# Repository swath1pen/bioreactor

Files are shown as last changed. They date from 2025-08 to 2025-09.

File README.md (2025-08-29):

# 3D Print Design for Customizable Microbial Bioreactor

This design is for a 100mL bioreactor for microbial electrochemical experimentation. 

### NIH 3D Print Database Deposit
https://3d.nih.gov/

### WebApp_beta
https://swath1pen.github.io/bioreactor

## Protocol.io for Fabrication Notes

1. **SLA Printing with FormLabs Printers**

2. **Fabrication of Gaskets**

## License

This project is open source and available under the [MIT License](LICENSE).

---

Happy experimenting!

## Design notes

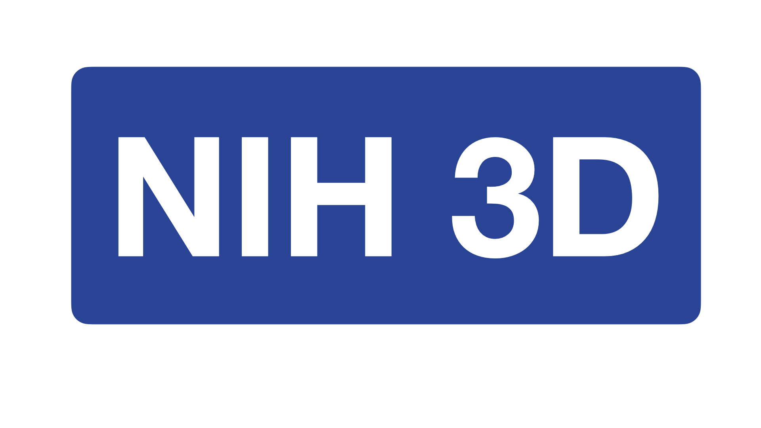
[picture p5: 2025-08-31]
logos/nih.png

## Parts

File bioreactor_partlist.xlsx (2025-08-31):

Purpose | Quantity | Part | Assembly | Link | Price | Quantity | Per Reactor | Price/Reactor
Sealing | 1 | O-Ring: 42 mm Nominal ID, 46 mm Nominal OD. | To seal cap with electrode comprtment and glass bottle. | https://www.grainger.com/product/O-Ring-42-mm-Nominal-Inside-714A76 | 14.13 | 5 | 2 | 5.652
 | 2 | 20mm OD 17m ID silicone custom rubber gasket | Lasercut from silicone sheets purchased from McMasterCarr | https://www.mcmaster.com/1460N11-1460N112/ | 17.13 | 100 | 2 | 0.3426
 | 1 | PTFE-faced silicone septum, 32 mm | To seal electrode compartment with bioreactor cap. | https://www.sigmaaldrich.com/US/en/product/aldrich/z411752 | 52.15 | 10 | 1 | 5.215
Gas Control | 1 | 0.2uM 13mM syringe filters | To ensure sterility during gas exchange. | https://www.thermofisher.com/order/catalog/product/720-1320?ISO_CODE=us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 | 392.62 | 100 | 1 | 3.9262
 | 2 | luer check valve | To control gas pressure release. | https://www.amazon.com/Medical-Grade-Plastic-Female-Diaphragm/dp/B0D78ZLYLP?gQT=1 | 52.61 | 10 | 2 | 10.522
Main Components | 1 | glass bottles 120mL | Main reactor vessel. | https://www.grainger.com/product/41U142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 | 37.21 | 24 | 1 | 1.550416667
 | 1 | Form Labs Biomed Clear Resin | 3D Print Material | https://formlabs.com/store/materials/biomed-clear-resin/ | 349 | 1000 | 60 | 20.94
 | 1 | Titanium wire | Connection to electrodes. | https://www.amazon.com/TEMCo-Titanium-Gauge-Surgical-Resistance/dp/B01AV6RF8M?gQT=1 | 16.7 | 100 | 1 | 0.167
 | 1 | Platinum wire | Counter electrode | https://www.flinnsci.com/platinum-wire-36-gauge-per-inch/p0145/ | 19.25 | 100 | 1 | 0.1925
 | 1 | graphite felt | Working electrode | https://www.avantorsciences.com/ie/en/product/2336090/carbon-99-felt-thickness-6-35-mm-0-250-in | 45 | 100 | 1.7 | 0.765
 | 1 | 20mm CEM FKB-PK-130 | Cation Exchange Membrane | https://www.fuelcellstore.com/fumasep-fkb | 32 | 100 | 1.7 | 0.544
Reference | 1 | Dri-REF2 | Leakless Ag/AgCl reference electrode | https://www.wpiinc.com/driref-2-dri-ref-reference-electrode-2-mm.html | 158 | 1 | 1 | 158
Outer Containment | 1 | Alligator clips | For connection to titanium wire. | https://www.amazon.com/WGGE-WG-026-Pieces-Colors-Alligator/dp/B06XX25HFX?sp_csd=d2lkZ2V0TmFtZT1zcF9hdGY | 5.99 | 10 | 3 | 1.797
 | 1 | Epoxy glue (5 min curing) | To seal clips into mason jar lid. | https://www.amazon.com/dp/B001Z3C3AG?_encoding=UTF8&ref_=cm_sw_r_cp_ud_dp_A05D7AQ3JB35AM0H55W2&th=1 | 5.97 | 1 | 1 | 5.97
 | 1 | tall mason jars | Outer countainment vessel. | https://www.amazon.com/Xylanor-Canning-airtight-Storage-Preserving/dp/B0DS23V3SJ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 | 22.99 | 6 | 1 | 3.831666667
 |  |  |  |  | 1220.75 |  |  | 219.4153833 | Dollars
 |  |  |  |  |  |  |  | 61.41538333

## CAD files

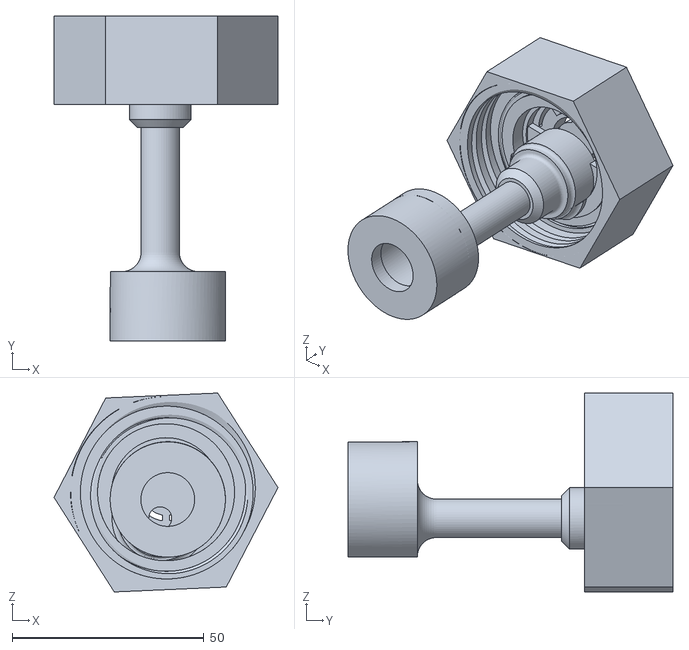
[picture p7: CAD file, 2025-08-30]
dist/bioreactor.stl
58.3 x 84.5 x 51.8

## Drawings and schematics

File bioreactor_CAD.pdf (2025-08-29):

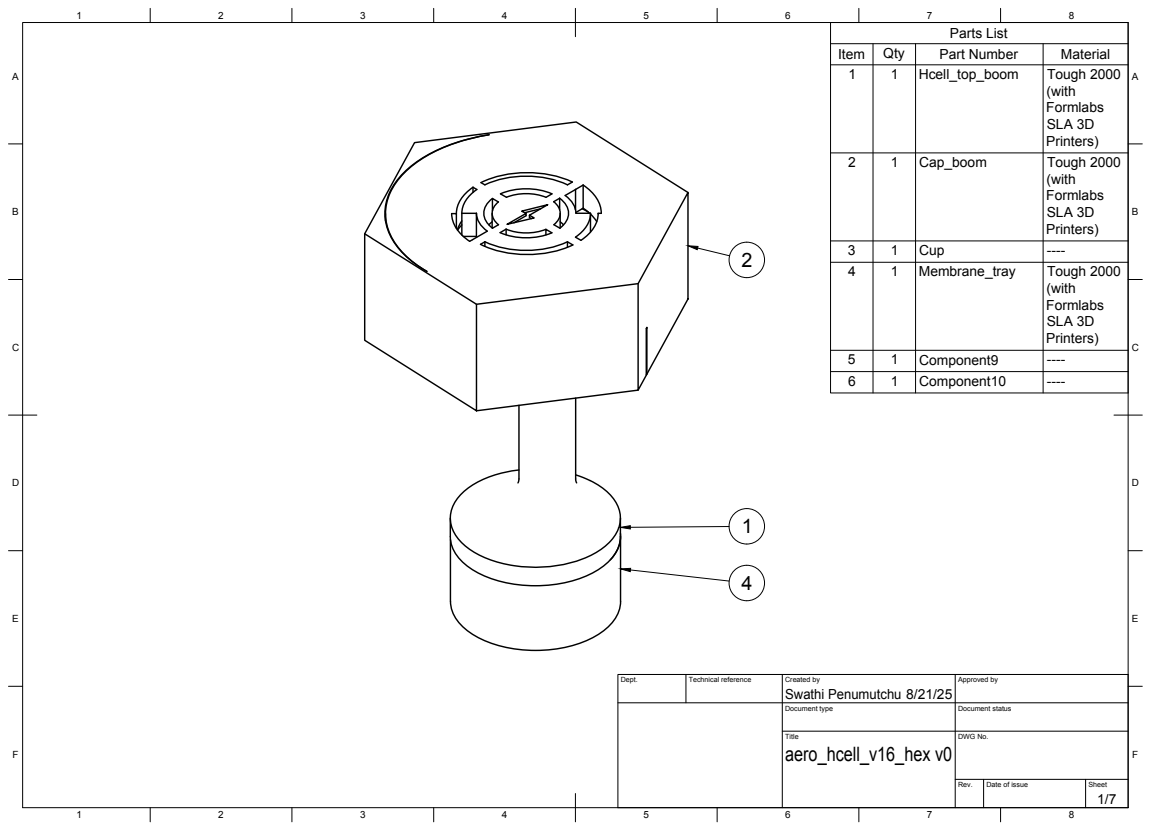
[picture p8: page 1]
Title; DWG No.; Rev.; Date of issue; Sheet; aero_hcell_v16_hex v0; Parts List

Item | Qty 1 | Hcell_top_boom Part Number | Tough 2000 Material 1

(with Formlabs SLA 3D Printers)

2 | 1 | Cap_boom | Tough 2000 (with Formlabs SLA 3D Printers)

3 | 1 | Cup | ----
4 | 1 | Membrane_tray | Tough 2000 (with Formlabs SLA 3D Printers)

5 | 1 | Component9 | ----
6 | 1 | Component10 | ----

Dept. | Technical reference | Created by Swathi Penumutchu 8/21/25 | Approved by

Document type | Document status

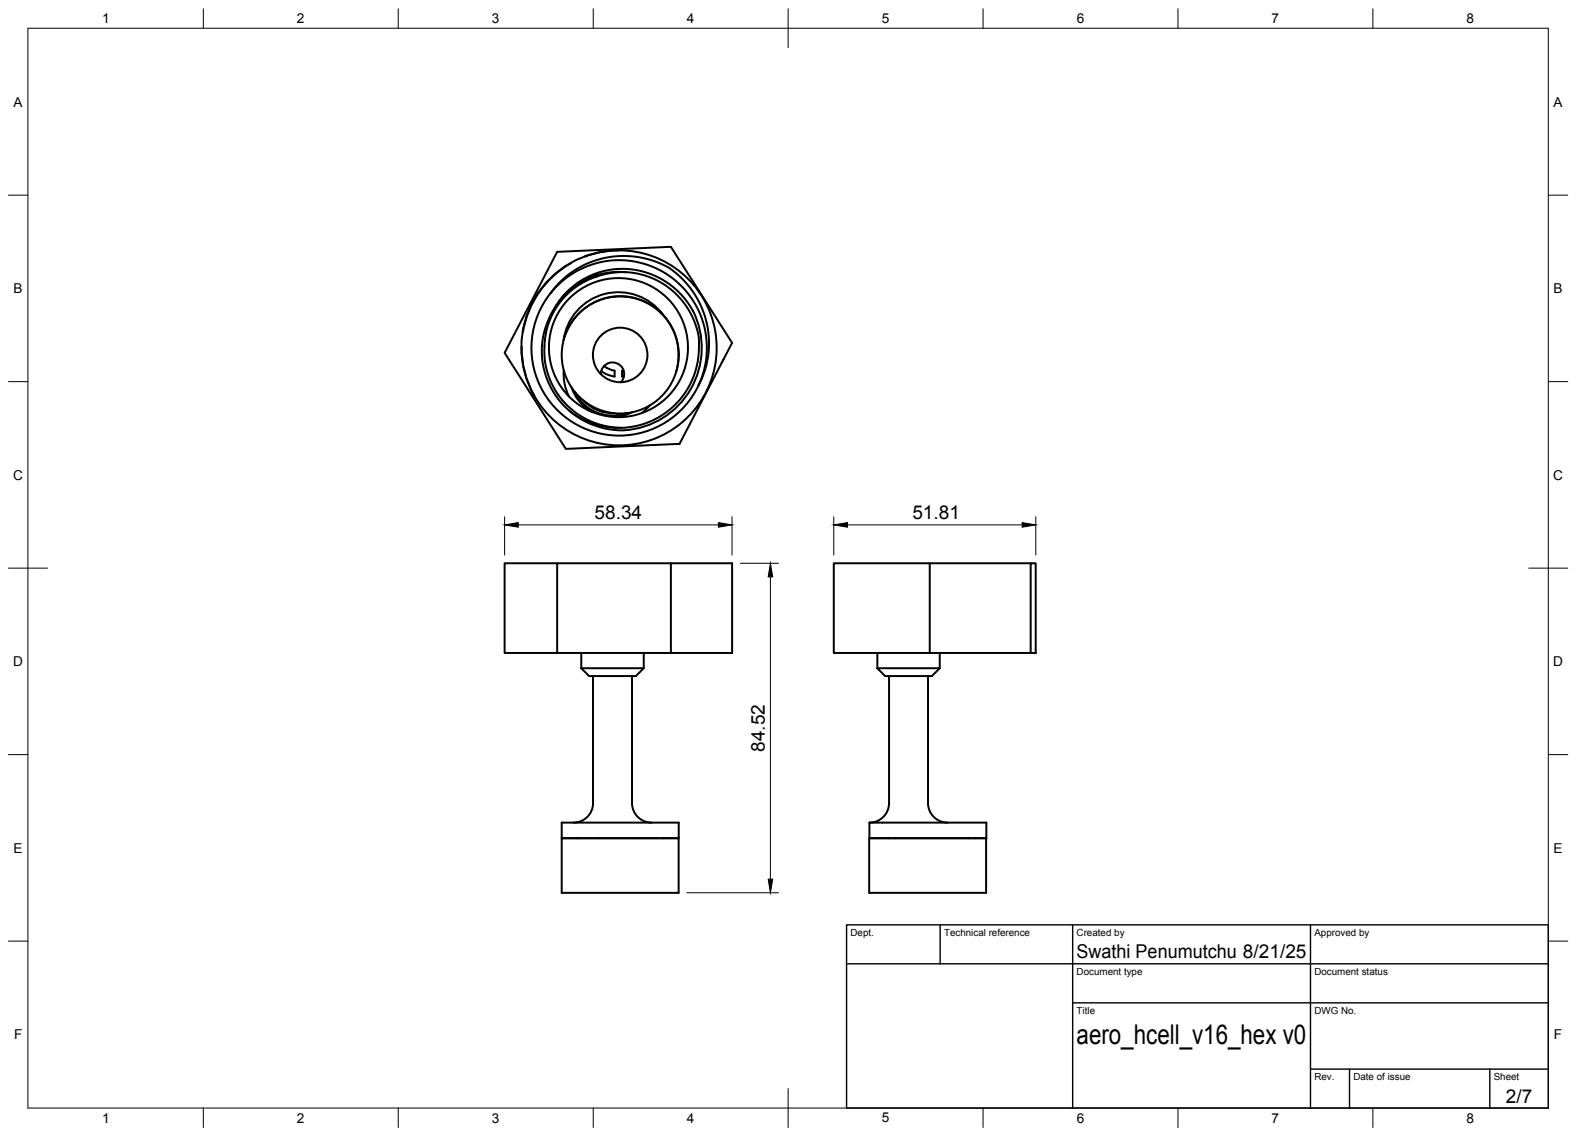
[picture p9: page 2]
Title; DWG No.; aero_hcell_v16_hex v0

Dept. | Technical reference | Created by Swathi Penumutchu 8/21/25 | Approved by

Document type | Document status

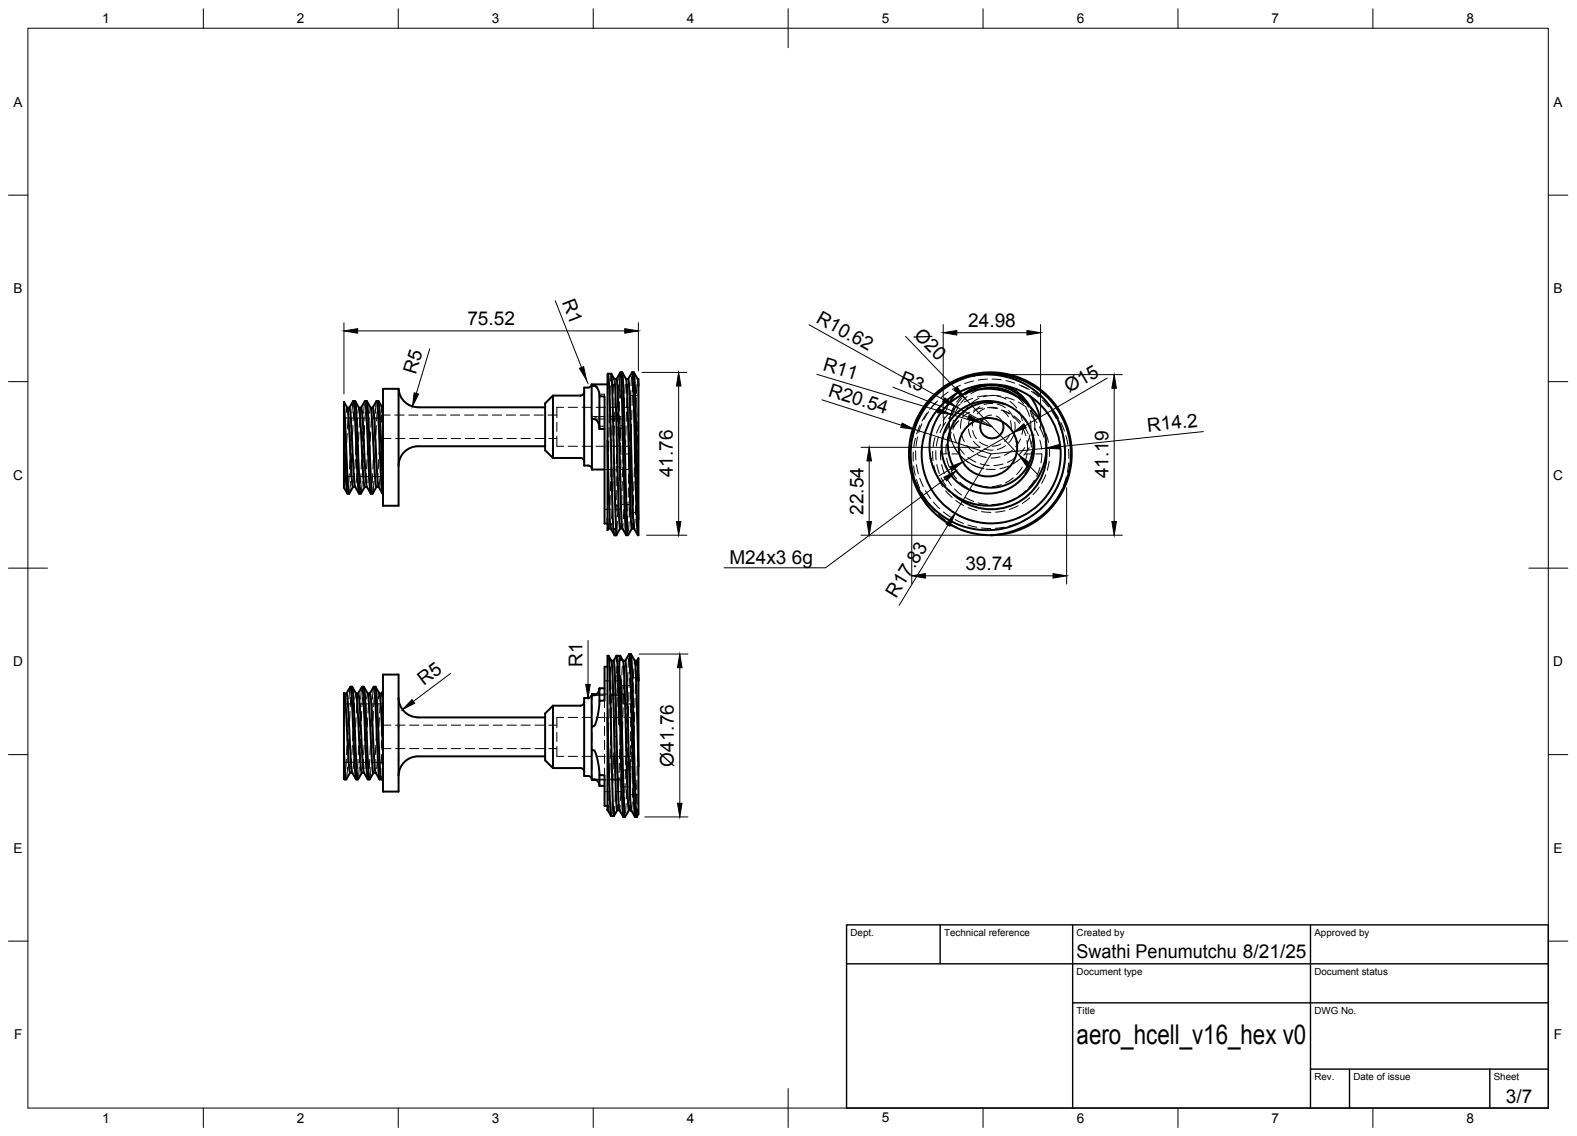
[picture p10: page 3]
Title; DWG No.; aero_hcell_v16_hex v0

Dept. | Technical reference | Created by Swathi Penumutchu 8/21/25 | Approved by

Document type | Document status

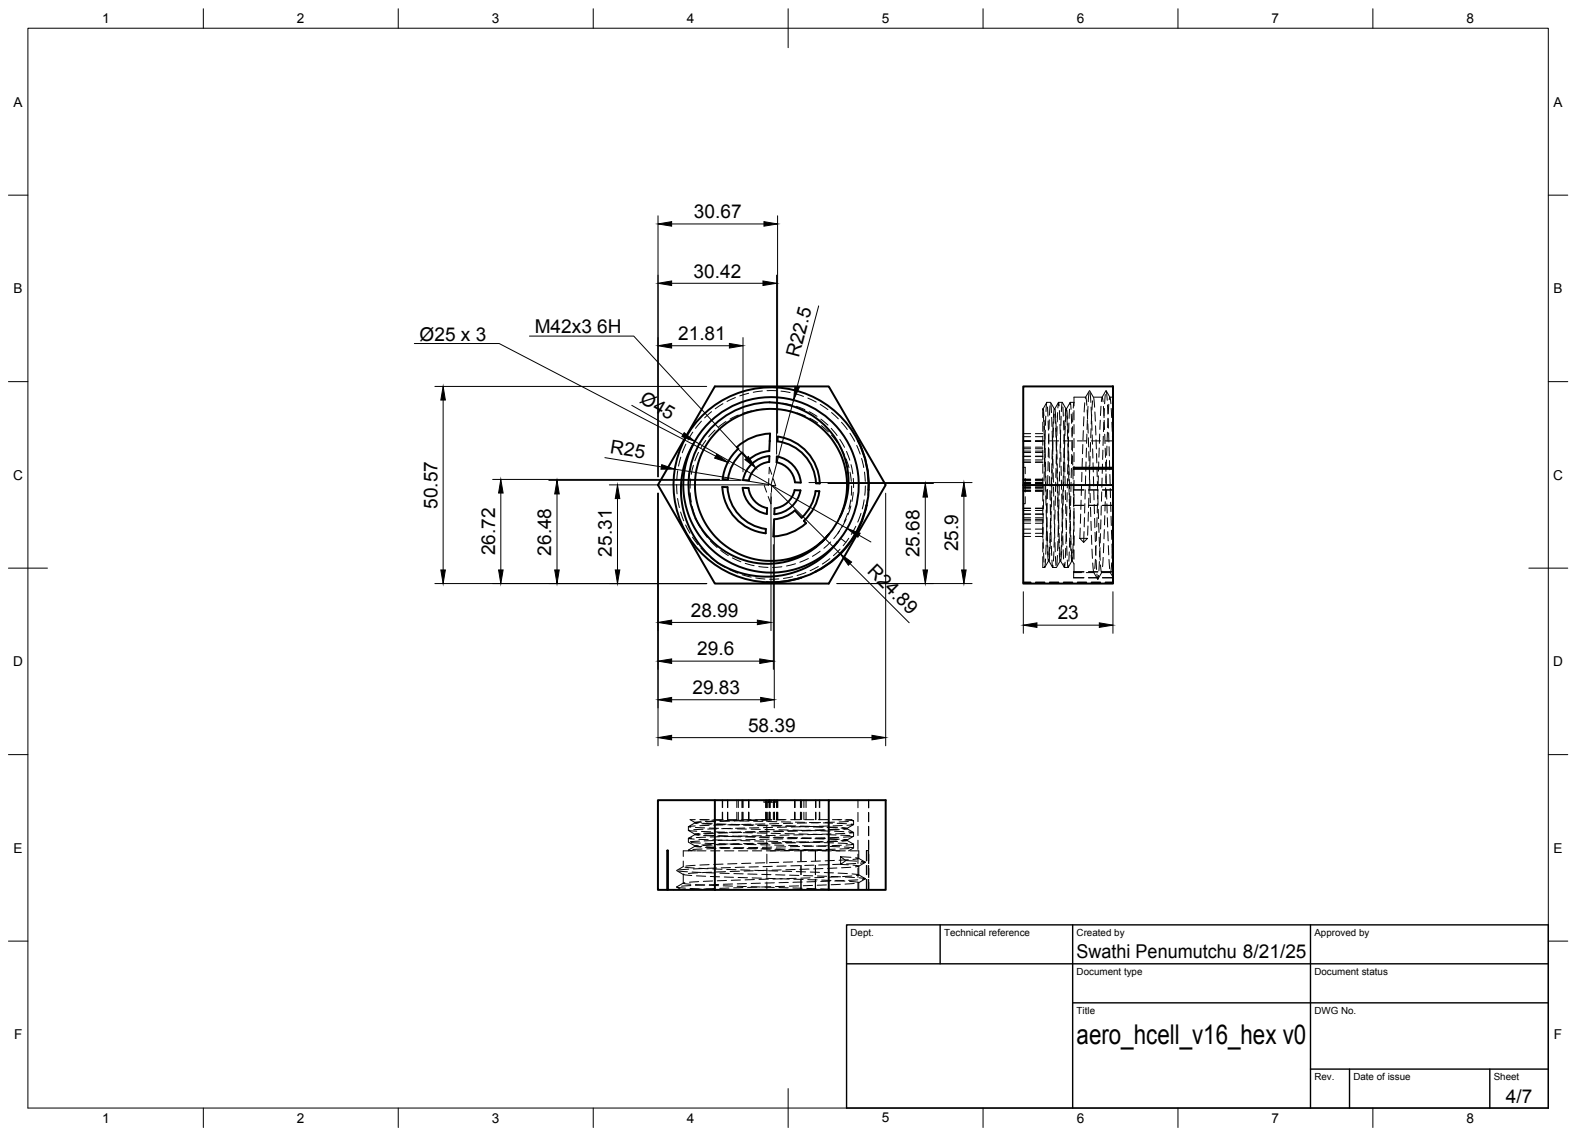
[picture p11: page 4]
Title; DWG No.; aero_hcell_v16_hex v0

Dept. | Technical reference | Created by Swathi Penumutchu 8/21/25 | Approved by

Document type | Document status
